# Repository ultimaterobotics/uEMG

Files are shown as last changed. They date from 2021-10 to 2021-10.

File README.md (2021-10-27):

# uEMG - 4-channel EMG device
This repository contains PCB design, firmware and PC program for analysing data (that one has hardly readable code for now, it's a work in progress with thousands lines of code dedicated to various signal processing approaches with only small part of them used in current version)

Firmware is in relatively good state. It depends on our nrf library: https://github.com/ultimaterobotics/urf_lib and requires bootloader: https://github.com/ultimaterobotics/uECG_bootloader

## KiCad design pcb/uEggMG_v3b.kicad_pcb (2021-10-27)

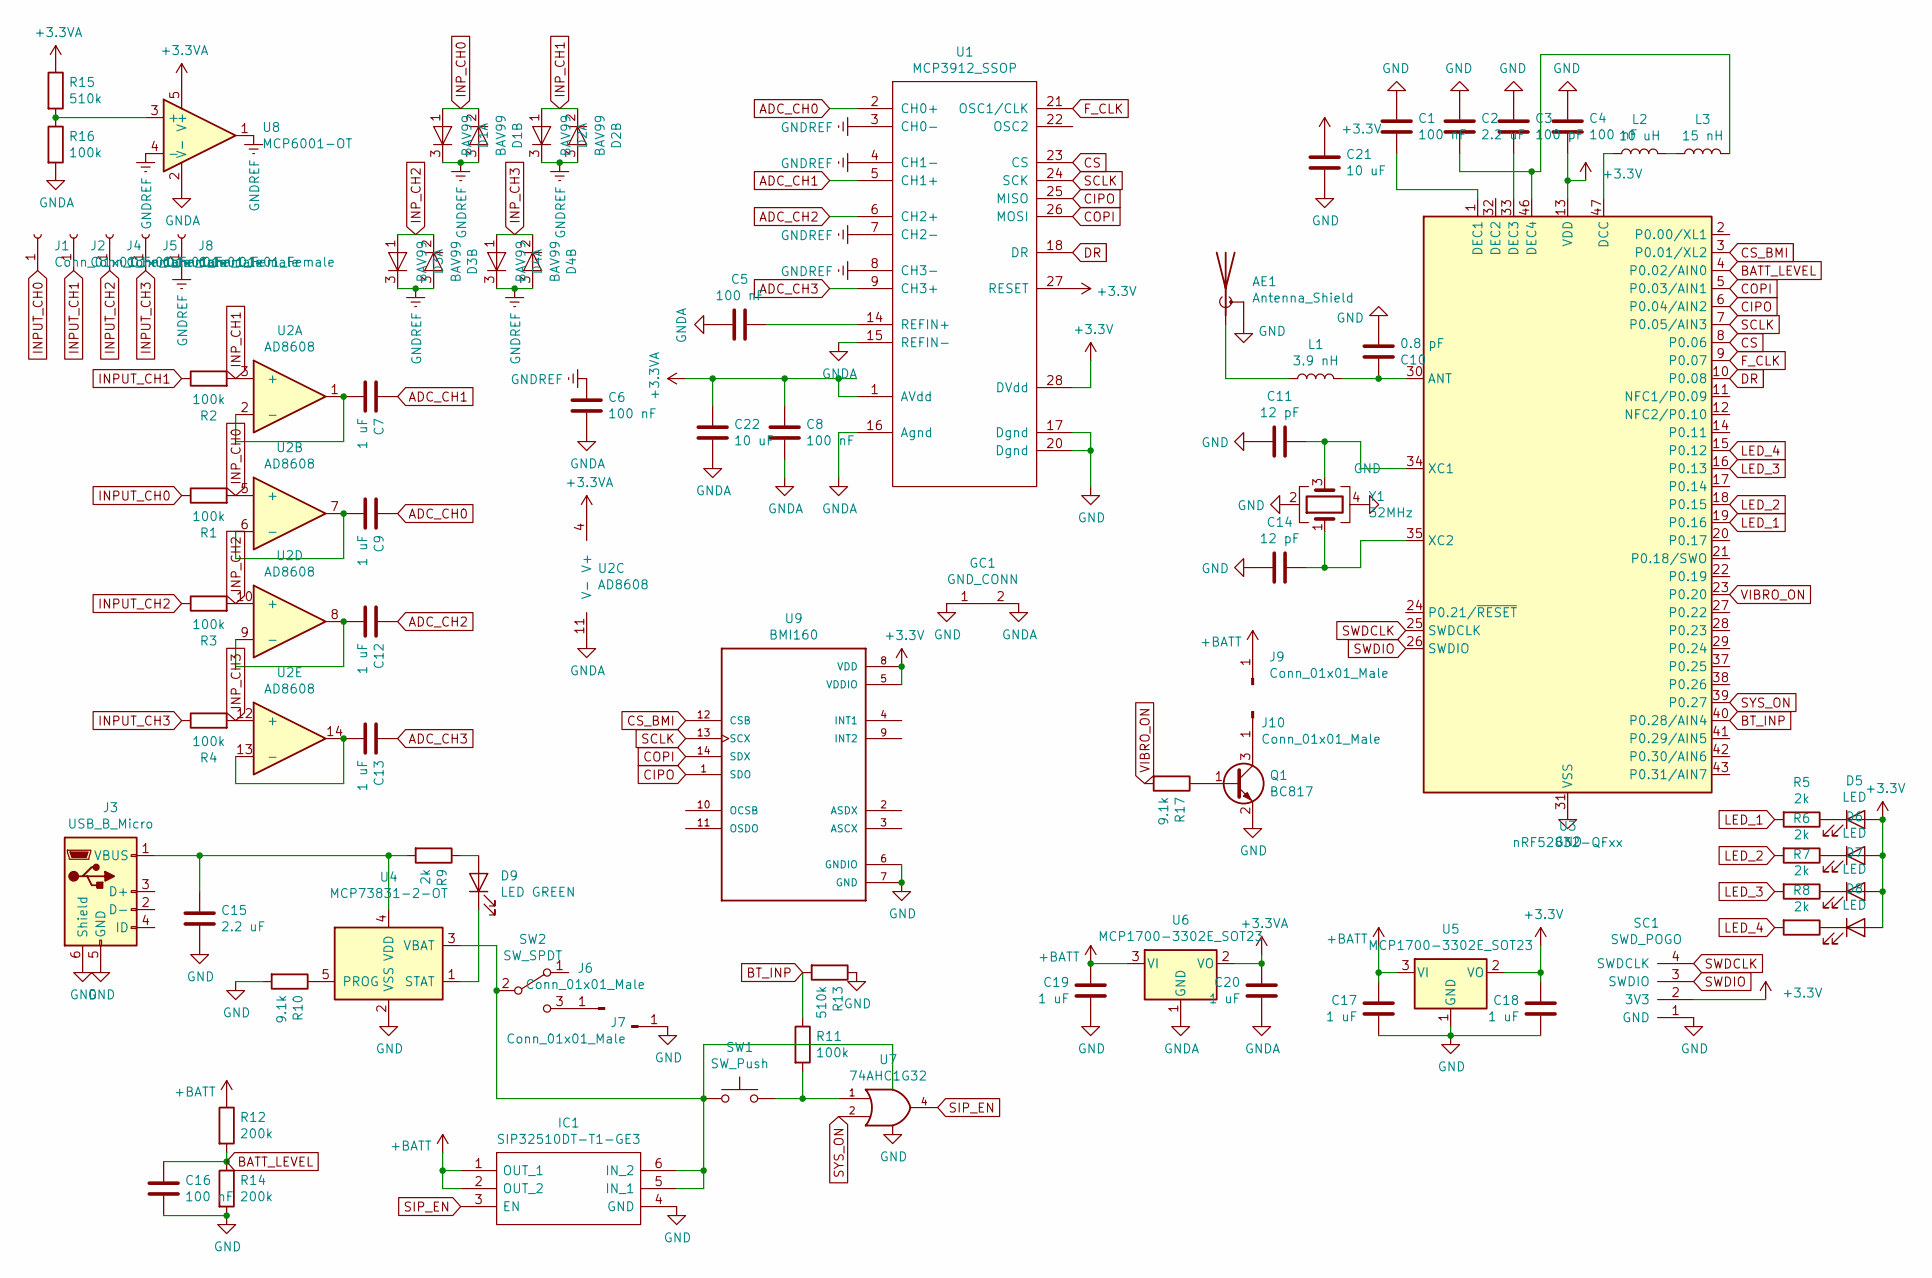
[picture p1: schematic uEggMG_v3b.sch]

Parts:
AE1: Antenna_Shield; U.FL_Hirose_U.FL-R-SMT-1_Vertical
C1, C4, C5, C6, C8, C16: 100 nF; C_0402_1005Metric
C2, C15: 2.2 uF; C_0402_1005Metric
C3: 100 pF; C_0402_1005Metric
C7, C9, C12, C13, C17, C18, C19, C20: 1 uF; C_0402_1005Metric
C10: 0.8 pF; C_0402_1005Metric
C11, C14: 12 pF; C_0402_1005Metric
C21, C22: 10 uF; C_0603_1608Metric
D1, D2, D3, D4: BAV99; SOT-23
D5, D6, D7, D8: LED; LED_0603_1608Metric
D9: LED GREEN; LED_0603_1608Metric
GC1: GND_CONN
IC1: SIP32510DT-T1-GE3; SOT95P284X110-6N; Manufacturer_Part_Number SIP32509DT-T1-GE3
J1, J2, J4, J5, J8: Conn_01x01_Female; textile_button_6mm
J3: USB_B_Micro; conn_usb_B_micro_smd_our
J6, J7, J9, J10: Conn_01x01_Male; PinHeader_1x01_P2.54mm_Vertical
L1: 3.9 nH; L_0402_1005Metric
L2: 10 uH; L_0603_1608Metric
L3: 15 nH; L_0402_1005Metric
Q1: BC817; SOT-23
R1, R2, R3, R4, R11, R16: 100k; R_0402_1005Metric
R5, R6, R7, R8, R9: 2k; R_0402_1005Metric
R10, R17: 9.1k; R_0402_1005Metric
R12, R14: 200k; R_0402_1005Metric
R13, R15: 510k; R_0402_1005Metric
SC1: SWD_POGO
SW1: SW_Push; BTN_HY_1185
SW2: SW_SPDT; SW_SPDT_PCM12
U1: MCP3912_SSOP; SSOP-28_5.3x10.2mm_P0.65mm
U2: AD8608; TSSOP-14_4.4x5mm_P0.65mm
U3: nRF52832-QFxx; QFN-48-1EP_6x6mm_Pitch0.4mm
U4: MCP73831-2-OT; SOT-23-5
U5, U6: MCP1700-3302E_SOT23; SOT-23
U7: 74AHC1G32; TSOT-23-5
U8: MCP6001-OT; SOT-23-5
U9: BMI160; PQFN50P300X250X88-14N
Y1: 32MHz; Crystal_SMD_2016-4Pin_2.0x1.6mm

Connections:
+3.3VA: C8.1, C20.2, C22.1, R15.1, U1.1 (AVdd), U2.4 (V+), U6.2 (VO), U8.5 (V+)
+3V3: C4.1, C18.2, C21.1, D5.2 (A), D6.2 (A), D7.2 (A), D8.2 (A), SC1.2 (3V3), U1.27 (RESET), U1.28 (DVdd), U3.13 (VDD), U3.36 (VDD), U3.48 (VDD), U5.2 (VO), U9.5 (VDDIO), U9.8 (VDD)
+BATT: C17.2, C19.2, IC1.1 (OUT_1), IC1.2 (OUT_2), J9.1, R12.1, U5.3 (VI), U6.3 (VI)
ADC_CH0: C9.1, U1.2 (CH0+)
ADC_CH1: C7.1, U1.5 (CH1+)
ADC_CH2: C12.1, U1.6 (CH2+)
ADC_CH3: C13.1, U1.9 (CH3+)
BATT_LEVEL: C16.2, R12.2, R14.1, U3.4 (P0.02/AIN0)
BT_INP: R11.1, R13.2, U3.40 (P0.28/AIN4)
CIPO: U1.25 (MISO), U3.6 (P0.04/AIN2), U9.1 (SDO)
COPI: U1.26 (MOSI), U3.5 (P0.03/AIN1), U9.14 (SDX)
CS: U1.23 (CS), U3.8 (P0.06)
CS_BMI: U3.3 (P0.01/XL2), U9.12 (CSB)
DR: U1.18 (DR), U3.10 (P0.08)
F_CLK: U1.21 (OSC1/CLK), U3.9 (P0.07)
GND: AE1.2 (Shield), C1.2, C2.2, C3.2, C4.2, C10.2, C11.1, C14.1, C15.1, C16.1, C17.1, C18.1, C19.1, C21.2, GC1.1, IC1.4 (GND), J3.5 (GND), J3.6 (Shield), J7.1, Q1.2 (E), R10.2, R13.1, R14.2, SC1.1 (GND), U1.17 (Dgnd), U1.20 (Dgnd), U3.31 (VSS), U3.45 (VSS), U3.49 (VSS), U4.2 (VSS), U5.1 (GND), U7.3 (GND), U9.6 (GNDIO), U9.7 (GND), Y1.2, Y1.4
GNDA: C5.2, C6.2, C8.2, C20.1, C22.2, GC1.2, R16.2, U1.10, U1.11, U1.12, U1.13, U1.15 (REFIN-), U1.16 (Agnd), U1.19, U2.11 (V-), U6.1 (GND), U8.2 (V-)
GNDREF: C6.1, D1.3 (K), D2.3 (K), D3.3 (K), D4.3 (K), J8.1, U1.3 (CH0-), U1.4 (CH1-), U1.7 (CH2-), U1.8 (CH3-), U8.1, U8.4 (-)
INPUT_CH0: J1.1, R1.1
INPUT_CH1: J2.1, R2.1
INPUT_CH2: J4.1, R3.1
INPUT_CH3: J5.1, R4.1
INP_CH0: D1.1 (A), D1.2 (K), R1.2, U2.5 (+)
INP_CH1: D2.1 (A), D2.2 (K), R2.2, U2.3 (+)
INP_CH2: D3.1 (A), D3.2 (K), R3.2, U2.10 (+)
INP_CH3: D4.1 (A), D4.2 (K), R4.2, U2.12 (+)
LED_1: R5.2, U3.19 (P0.16)
LED_2: R6.2, U3.18 (P0.15)
LED_3: R7.2, U3.16 (P0.13)
LED_4: R8.2, U3.15 (P0.12)
unnamed: AE1.1 (A), L1.1
unnamed: C1.1, U3.1 (DEC1)
unnamed: C2.1, L3.2, U3.46 (DEC4)
unnamed: C3.1, U3.33 (DEC3)
unnamed: C5.1, U1.14 (REFIN+)
unnamed: C7.2, U2.1, U2.2 (-)
unnamed: C9.2, U2.6 (-), U2.7
unnamed: C10.1, L1.2, U3.30 (ANT)
unnamed: C11.2, U3.34 (XC1), Y1.3
unnamed: C12.2, U2.8, U2.9 (-)
unnamed: C13.2, U2.13 (-), U2.14
unnamed: C14.2, U3.35 (XC2), Y1.1
unnamed: C15.2, J3.1 (VBUS), R9.2, U4.4 (VDD)
unnamed: D5.1 (K), R5.1
unnamed: D6.1 (K), R6.1
unnamed: D7.1 (K), R7.1
unnamed: D8.1 (K), R8.1
unnamed: D9.1 (K), U4.1 (STAT)
unnamed: D9.2 (A), R9.1
unnamed: J6.1, SW2.3 (C)
unnamed: J10.1, Q1.3 (C)
unnamed: L2.1, U3.47 (DCC)
unnamed: L2.2, L3.1
unnamed: Q1.1 (B), R17.1
unnamed: R10.1, U4.5 (PROG)
unnamed: R11.2, SW1.2, U7.1
unnamed: R15.2, R16.1, U8.3 (+)
SCLK: U1.24 (SCK), U3.7 (P0.05/AIN3), U9.13 (SCX)
SIP_EN: IC1.3 (EN), U7.4
SWDCLK: SC1.4 (SWDCLK), U3.25 (SWDCLK)
SWDIO: SC1.3 (SWDIO), U3.26 (SWDIO)
SYS_ON: U3.39 (P0.27), U7.2
VCC: IC1.5 (IN_1), IC1.6 (IN_2), SW1.1, SW2.2 (B), U4.3 (VBAT), U7.5 (VCC)
VIBRO_ON: R17.2, U3.23 (P0.20)

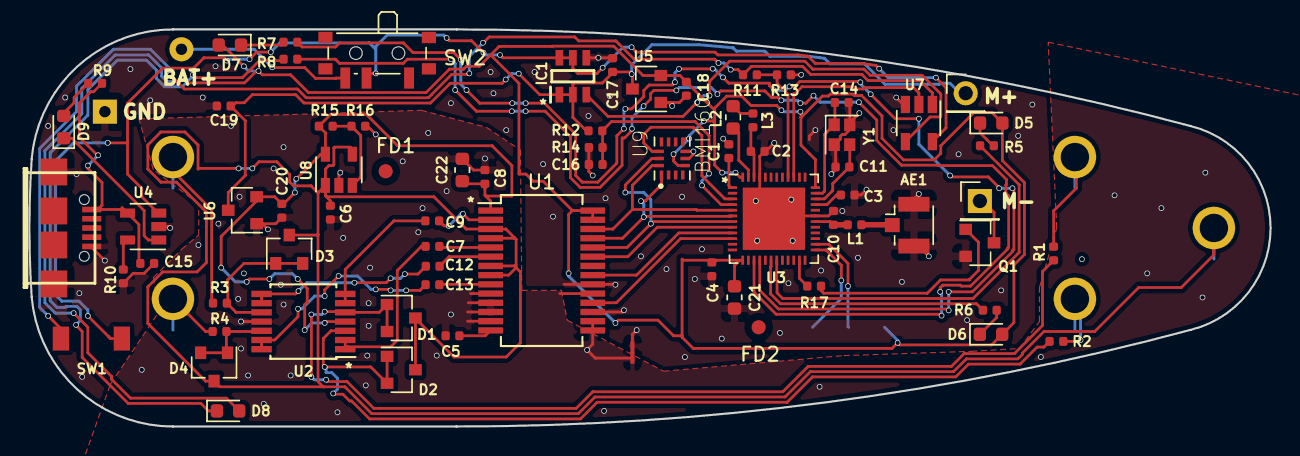
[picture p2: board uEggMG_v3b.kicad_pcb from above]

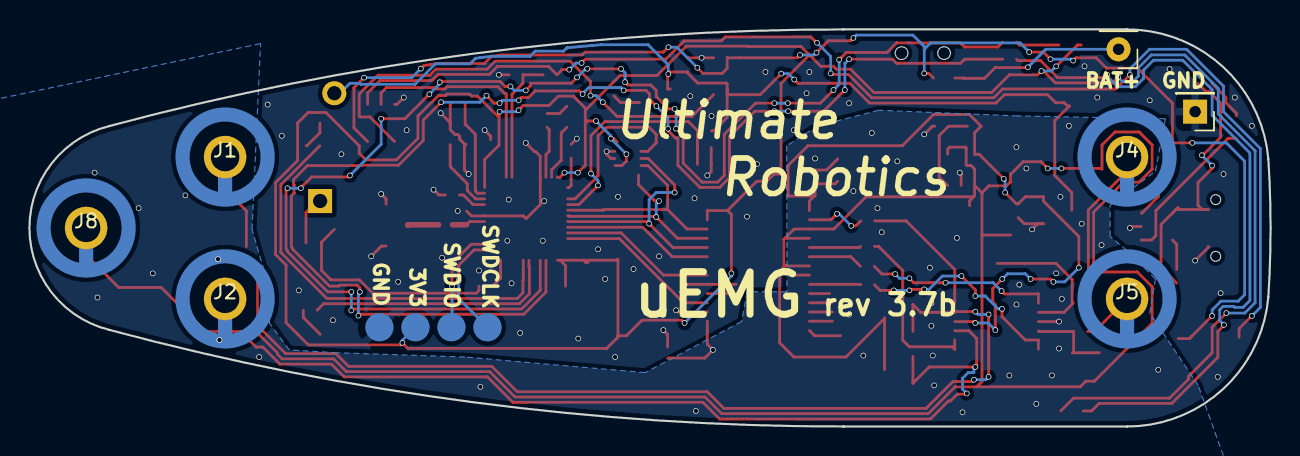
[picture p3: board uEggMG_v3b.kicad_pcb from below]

Board: 2 copper layers, 87.5 x 28.0 mm, 80 parts (8 on the bottom side), 64 nets.

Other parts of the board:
FD1, FD2: Fiducial_1mm_Dia_2mm_Outer

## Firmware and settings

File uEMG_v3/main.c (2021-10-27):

/**
 */

#include <stdbool.h>
#include <stdint.h>
#include <math.h>
#include "nrf.h"
#include "mcp3912.h"
#include "bmi160.h"
#include "leds.h"
#include "urf_star_protocol.h"
#include "urf_timer.h"
#include "imu_fusion.h"

//openocd -f interface/stlink-v2.cfg -f target/nrf52.cfg
//flash write_image erase _build/nrf52832_xxaa.hex

uint8_t pin_button = 28;
uint8_t pin_syson = 27;

float battery_mv = 3500; //by default non zero to prevent power off before actual measurement
int battery_low_threshold = 3200;

uint8_t battery_level = 0;
uint8_t packet_id = 0;
uint8_t data_packet[258];

uint8_t unsent_cnt = 0;

uint8_t mcp_data_id = 0;
int mcp_buffer[130];
uint8_t mcp_buf_pos = 0;
uint8_t mcp_buf_len = 128;
uint8_t mcp_cnt = 0;

uint8_t param_send_id = 0;

uint8_t emg_raw_data_send = 1;

enum param_sends
{
	param_batt = 0,
	param_imu_steps,
	param_end
};

uint8_t part2_packet = 0;

void prepare_data_packet()
{
	uint8_t idx = 0;
	packet_id++;
	if(packet_id > 128) packet_id = 0;
	data_packet[idx++] = packet_id;
	data_packet[idx++] = 0; //fill in the end
	uint32_t unit_id = NRF_FICR->DEVICEID[1];
	data_packet[idx++] = (unit_id>>24)&0xFF;
	data_packet[idx++] = (unit_id>>16)&0xFF;
	data_packet[idx++] = (unit_id>>8)&0xFF;
	data_packet[idx++] = (unit_id)&0xFF;
	uint8_t send_cnt = 16;
	if(emg_raw_data_send)
	{
		send_cnt = 32;
		data_packet[idx++] = 220+send_cnt;
	}
	else
	{
		if(part2_packet)
		{
			data_packet[idx++] = 100+send_cnt;
			part2_packet = 0;
		}
		else
			data_packet[idx++] = 200+send_cnt;
	}

	param_send_id++;
	if(param_send_id == param_end) param_send_id = 0;

	data_packet[idx++] = param_send_id;
	if(param_send_id == param_batt)
	{
		data_packet[idx++] = battery_level;
		data_packet[idx++] = 100; //version_id
		data_packet[idx++] = 0;
	}
	if(param_send_id == param_imu_steps)
	{
		sBMI160 *bmi = bmi160_get_data();
		int steps = bmi->step_cnt;
		data_packet[idx++] = (steps>>8)&0xFF;
		data_packet[idx++] = steps&0xFF;
		data_packet[idx++] = 0;
	}
	
	data_packet[idx++] = mcp_data_id;
	int start_cnt = mcp_buf_pos - send_cnt;
	if(start_cnt < 0) start_cnt += mcp_buf_len;
	for(int n = 0; n < send_cnt; n++)
	{
		data_packet[idx++] = mcp_buffer[start_cnt]>>8;
		data_packet[idx++] = mcp_buffer[start_cnt]&0xFF;
		start_cnt++;
		if(start_cnt >= mcp_buf_len) start_cnt = 0;
	}
	
//	if(!emg_raw_data_send)
	{
		sBMI160 *bmi = bmi160_get_data();
		int16_t b_ax = bmi->raX;
		int16_t b_ay = bmi->raY;
		int16_t b_az = bmi->raZ;
		data_packet[idx++] = (b_ax>>8)&0xFF;
		data_packet[idx++] = b_ax&0xFF;
		data_packet[idx++] = (b_ay>>8)&0xFF;
		data_packet[idx++] = b_ay&0xFF;
		data_packet[idx++] = (b_az>>8)&0xFF;
		data_packet[idx++] = b_az&0xFF;

		int16_t b_wx = bmi->rwX;
		int16_t b_wy = bmi->rwY;
		int16_t b_wz = bmi->rwZ;
		data_packet[idx++] = (b_wx>>8)&0xFF;
		data_packet[idx++] = b_wx&0xFF;
		data_packet[idx++] = (b_wy>>8)&0xFF;
		data_packet[idx++] = b_wy&0xFF;
		data_packet[idx++] = (b_wz>>8)&0xFF;
		data_packet[idx++] = b_wz&0xFF;
		
		sQ *cur_q = imu_fusion_get_q();
		b_wx = cur_q->x * 30000.0f;
		b_wy = cur_q->y * 30000.0f;
		b_wz = cur_q->z * 30000.0f;
		int16_t b_ww = cur_q->w * 30000.0f;
		data_packet[idx++] = (b_wx>>8)&0xFF;
		data_packet[idx++] = b_wx&0xFF;
		data_packet[idx++] = (b_wy>>8)&0xFF;
		data_packet[idx++] = b_wy&0xFF;
		data_packet[idx++] = (b_wz>>8)&0xFF;
		data_packet[idx++] = b_wz&0xFF;
		data_packet[idx++] = (b_ww>>8)&0xFF;
		data_packet[idx++] = b_ww&0xFF;
	}
	data_packet[1] = idx;
}

float avg_emg[4] = {0, 0, 0, 0};
int emg_lvl[4] = {0, 0, 0, 0};
int spectr_part2_pending = 0;
uint32_t spectr_part2_time = 0;
int mcp_buf_sp2[16];

int push_mcp_data()
{
//	if(emg_mode)	
	if(mcp_fft_process())
	{
		if(emg_raw_data_send)
		{
			float *dat_base = mcp_fft_get_raw();
			for(int c = 0; c < 4; c++)
			{
				float *dat = dat_base + c*8;
				for(int x = 0; x < 8; x++)
				{
					mcp_buffer[mcp_buf_pos++] = dat[x];
					if(mcp_buf_pos >= mcp_buf_len) mcp_buf_pos = 0;
				}
			}
		}
		else
		{
//			spectr_part2_pending = 1;
//			spectr_part2_time = millis();
			float *sp_base = mcp_fft_get_spectr();
			for(int c = 0; c < 4; c++)
			{
				float *sp = sp_base + c*8;

				float avg_center = 0;
				float low_part = 0;
				float high_part = 0;

				for(int x = 0; x < 4; x++)
				{
					if(x > 0) avg_center += sp[x];
					if(x == 0) low_part += sp[x];
					else high_part += sp[x];
					float vv = sp[x];
					if(vv < 0) vv = 0;
					if(vv > 65535) vv = 65535;
					mcp_buffer[mcp_buf_pos++] = vv;
					if(mcp_buf_pos >= mcp_buf_len) mcp_buf_pos = 0;

					float vv2 = sp[4+x];
					if(vv2 < 0) vv2 = 0;
					if(vv2 > 65535) vv2 = 65535;
					mcp_buf_sp2[c*4+x] = vv2;
				}
				
				
				low_part /= 2.0f;
				high_part /= 6.0f;
			
				float h_coeff = 2.0f*high_part / (low_part + high_part + 0.001f);

				avg_center *= 0.03f * h_coeff;
			
				avg_emg[c] *= 0.8f;
				avg_emg[c] += 0.2f*avg_center;

				emg_lvl[c] = avg_emg[c] * 100.0f;
				if(avg_emg[c] > 650) emg_lvl[c] = 65000;

			}
			static uint32_t last_led_ms = 0;
			uint32_t ms = millis();
			if(ms - last_led_ms > 30)
			{
				last_led_ms = ms;
				float led_scale = 1.0;
				int l1 = avg_emg[0] * led_scale;
				int l2 = avg_emg[1] * led_scale;
				int l3 = avg_emg[2] * led_scale;
				int l4 = avg_emg[3] * led_scale;
				if(l1 > 255) l1 = 255;
				if(l2 > 255) l2 = 255;
				if(l3 > 255) l3 = 255;
				if(l4 > 255) l4 = 255;
				leds_pulse(l1, l2, l3, l4, 100);
//				leds_pulse(255, 255, 0, 0, 100);
			}
		}
		mcp_data_id++;
//		leds_set(255*((ms%2000)>1000), 0, 0, 0);
		return 1;
	}
	return 0;
}


void fast_clock_start()
{
	NRF_CLOCK->EVENTS_HFCLKSTARTED = 0;
	NRF_CLOCK->TASKS_HFCLKSTART = 1;
	while (NRF_CLOCK->EVENTS_HFCLKSTARTED == 0) {}
}
void slow_clock_start()
{
	NRF_CLOCK->LFCLKSRC = 0;
	NRF_CLOCK->TASKS_LFCLKSTART = 1;
	while (NRF_CLOCK->EVENTS_LFCLKSTARTED == 0) {}
}
void fast_clock_stop()
{
	slow_clock_start();
//	NRF_CLOCK->EVENTS_LFCLKSTARTED = 0;
//	NRF_CLOCK->TASKS_LFCLKSTART = 1;
//	while (NRF_CLOCK->EVENTS_LFCLKSTARTED == 0) {}
	NRF_CLOCK->TASKS_HFCLKSTOP = 1;
}


void mode_lowbatt()
{
//	set_led(0);
//	nrf_delay_ms(1);
//	mcp3912_turnoff();
	time_stop();
	fast_clock_stop();
	NRF_SPI0->ENABLE = 0;
	leds_pulse(0, 0, 0, 0, 1);
	delay_ms(2);
	NRF_GPIO->OUTCLR = 1<<pin_syson;
//	nrf_delay_ms(1);
	NRF_POWER->TASKS_LOWPWR = 1;
//	NRF_POWER->DCDCEN = 1;
	NRF_POWER->SYSTEMOFF = 1;
}
void stop_rtc()
{
	NRF_RTC1->TASKS_STOP = 1;
}
void start_rtc()
{
	stop_rtc();
	NRF_RTC1->TASKS_CLEAR = 1;
	NRF_RTC1->CC[0] = 220;
	NRF_RTC1->CC[1] = 0xFFFF;
	NRF_RTC1->CC[2] = 0xFFFF;
	NRF_RTC1->CC[3] = 0xFFFF;
	NRF_RTC1->PRESCALER = 0x3CFFFF;
	NRF_RTC1->INTENSET = (1<<16); //CC0 event
	NVIC_EnableIRQ(RTC1_IRQn);
	NRF_RTC1->TASKS_START = 1;
}
void RTC1_IRQHandler(void)
{
	/* Update compare counter */
	if (NRF_RTC1->EVENTS_COMPARE[0] != 0)
	{
		NRF_RTC1->EVENTS_COMPARE[0] = 0;
		NRF_RTC1->TASKS_CLEAR = 1;  // Clear Counter		    
//		if(U32_delay_ms) U32_delay_ms--; // used in V_hw_delay_ms()
		__SEV(); // to avoid race condition
		stop_rtc();
	}
}

void read_battery()
{
	
	uint32_t result = 0;
	
	// Configure SAADC singled-ended channel, Internal reference (0.6V) and 1/6 gain.
	NRF_SAADC->CH[0].CONFIG = (SAADC_CH_CONFIG_GAIN_Gain1_6    << SAADC_CH_CONFIG_GAIN_Pos) |
							(SAADC_CH_CONFIG_MODE_SE         << SAADC_CH_CONFIG_MODE_Pos) |
							(SAADC_CH_CONFIG_REFSEL_Internal << SAADC_CH_CONFIG_REFSEL_Pos) |
							(SAADC_CH_CONFIG_RESN_Bypass     << SAADC_CH_CONFIG_RESN_Pos) |
							(SAADC_CH_CONFIG_RESP_Bypass     << SAADC_CH_CONFIG_RESP_Pos) |
							(SAADC_CH_CONFIG_TACQ_3us        << SAADC_CH_CONFIG_TACQ_Pos);

	// Configure the SAADC channel with VDD as positive input, no negative input(single ended).
	NRF_SAADC->CH[0].PSELP = SAADC_CH_PSELP_PSELP_AnalogInput0 << SAADC_CH_PSELP_PSELP_Pos;
	NRF_SAADC->CH[0].PSELN = SAADC_CH_PSELN_PSELN_NC << SAADC_CH_PSELN_PSELN_Pos;

	// Configure the SAADC resolution.
	NRF_SAADC->RESOLUTION = SAADC_RESOLUTION_VAL_14bit << SAADC_RESOLUTION_VAL_Pos;

	// Configure result to be put in RAM at the location of "result" variable.
	NRF_SAADC->RESULT.MAXCNT = 1;
	NRF_SAADC->RESULT.PTR = (uint32_t)&result;

	// No automatic sampling, will trigger with TASKS_SAMPLE.
	NRF_SAADC->SAMPLERATE = SAADC_SAMPLERATE_MODE_Task << SAADC_SAMPLERATE_MODE_Pos;

	// Enable SAADC (would capture analog pins if they were used in CH[0].PSELP)
	NRF_SAADC->ENABLE = SAADC_ENABLE_ENABLE_Enabled << SAADC_ENABLE_ENABLE_Pos;


	static int cal_cnt = 0;
	cal_cnt++;
	if(0)if(cal_cnt > 1000)
	{
		cal_cnt = 0;
		// Calibrate the SAADC (only needs to be done once in a while)
		NRF_SAADC->TASKS_CALIBRATEOFFSET = 1;
		while (NRF_SAADC->EVENTS_CALIBRATEDONE == 0);
		NRF_SAADC->EVENTS_CALIBRATEDONE = 0;
		while (NRF_SAADC->STATUS == (SAADC_STATUS_STATUS_Busy <<SAADC_STATUS_STATUS_Pos));
	}

	// Start the SAADC and wait for the started event.
	NRF_SAADC->TASKS_START = 1;
	while (NRF_SAADC->EVENTS_STARTED == 0);
	NRF_SAADC->EVENTS_STARTED = 0;

	// Do a SAADC sample, will put the result in the configured RAM buffer.
	NRF_SAADC->TASKS_SAMPLE = 1;
	while (NRF_SAADC->EVENTS_END == 0);
	NRF_SAADC->EVENTS_END = 0;

// Convert the result to voltage
// Result = [V(p) - V(n)] * GAIN/REFERENCE * 2^(RESOLUTION)
// Result = (VDD - 0) * ((1/6) / 0.6) * 2^14
// VDD = Result / 4551.1
//  precise_result = (float)result / 4551.1f;
//  precise_result; // to get rid of set but not used warning

	// Stop the SAADC, since it's not used anymore.
	NRF_SAADC->TASKS_STOP = 1;
	while (NRF_SAADC->EVENTS_STOPPED == 0);
	NRF_SAADC->EVENTS_STOPPED = 0;
	
	float res = result;
	//16384 = 3600 mV on A0
	res = res * 3600.0f / 16384.0f; //now res is in mv
	res *= 2.0f; //1:2 divider on the battery measurement
	battery_mv = res;
	res -= 2000.0f; //everything below 2V is too low for a battery
	if(res < 0)
	{
		battery_level = 0;
		return;
	}
	if(res > 2550) //shouldn't ever happen - 4.55v on the battery is way too much
	{
		battery_level = 255;
		return;
	}
	battery_level = res / 10;
	return;
}


void mode_idle()
{
//	leds_pause();
	time_pause();
	NRF_POWER->TASKS_LOWPWR = 1;
}
void mode_resume_idle()
{
	NRF_POWER->TASKS_CONSTLAT = 1;
	time_resume();
//	leds_resume();
}

void low_power_cycle()
{
	NRF_RADIO->POWER = 0;
//	mode_idle();
	__WFI();
//	mode_resume_idle();
	NRF_RADIO->POWER = 1;
}


enum
{
	radio_mode_fast = 0,
	radio_mode_ble,
	radio_mode_fast64
};

uint8_t radio_mode = radio_mode_fast64;//radio_mode_ble;
/*
void RADIO_IRQHandler()
{
	if(radio_mode == radio_mode_fast || radio_mode == radio_mode_fast64)
		fr_irq_handler();
	if(radio_mode == radio_mode_ble)
		ble_irq_handler();
}*/

void switch_to_ble()
{
//	fr_disable();
//	fr_poweroff();
//	config_ble_adv();
}

void switch_to_fr32()
{
//	fr_disable();
//	fr_poweroff();
//	fr_init(32);
//	fr_listen();	
}

void switch_to_fr48()
{
//	fr_disable();
//	fr_poweroff();
//	fr_init(48);
//	fr_listen();	
}
void switch_to_fr64()
{
//	fr_disable();
//	fr_poweroff();
//	fr_init(64);
//	fr_listen();	
}

void process_btn_short()
{
	emg_raw_data_send = !emg_raw_data_send;
/*	if(radio_mode == radio_mode_ble)
	{
		radio_mode = radio_mode_fast64;
		switch_to_fr64();
	}
	else if(radio_mode == radio_mode_fast64)
	{
		radio_mode = radio_mode_fast;
		switch_to_fr32();
	}
	else
	{
		radio_mode = radio_mode_ble;
		switch_to_ble();
	}*/
}

void process_btn_long()
{
	NRF_GPIO->OUTCLR = 1<<pin_syson;
}

int main(void)
{
	int init_ok = 1;
	
	NRF_UICR->NFCPINS = 0;

	NRF_GPIO->PIN_CNF[pin_button] = 0;

	fast_clock_start();
	time_start();
	NRF_GPIO->DIRSET = 1<<pin_syson;
	NRF_GPIO->OUTSET = 1<<pin_syson;
	leds_init();

//	NRF_POWER->DCDCEN = 1;

	for(int x = 0; x < 4; x++)
	{
		leds_pulse((x==0)*255, (x==1)*255, (x==2)*255, (x==3)*255, 250);
		delay_ms(300);
	}
//	leds_set_driver(55);
//	leds_set(255, 60, 120);
//	leds_set(0, 0, 0, 0);
//	delay_ms(300);

//	if(radio_mode == radio_mode_ble)
//		config_ble_adv();
//	if(radio_mode == radio_mode_fast)
//	{
//		fr_init(32);
//		fr_listen();
//	}
//	if(radio_mode == radio_mode_fast64)
//	{
//		fr_init(64);
//		fr_listen();
//	}
	star_init(21, 1000, 2000, 0);

	leds_pulse(255, 255, 255, 0, 200);
	
	init_mcp3912(4, 3, 5, 6, 8);
	leds_pulse(0, 0, 0, 0, 10);
	if(!mcp3912_is_ok())
	{
		init_ok = 0;
		leds_pulse(255, 0, 0, 0, 1000);
		delay_ms(1200);
		leds_pulse(255, 0, 255, 0, 1000);
		delay_ms(1200);
	}
	bmi160_init(4, 3, 5, 1, 20);
	if(!bmi160_is_ok())
	{
		init_ok = 0;
		leds_pulse(255, 0, 0, 0, 1000);
		delay_ms(1200);
		leds_pulse(255, 255, 0, 0, 1000);
		delay_ms(1200);
	}
	if(NRF_GPIO->IN & 1<<pin_button)
	{
		leds_pulse(255, 0, 0, 0, 1000);
		delay_ms(1200);
		leds_pulse(0, 0, 255, 0, 1000);
		delay_ms(1200);
	}
	

//	leds_set(0, 255, 0);

	delay_ms(100);

	uint32_t last_sent_ms = 0;
	uint32_t btn_on = 0;
	uint32_t btn_off = 0;

	NRF_RNG->TASKS_START = 1;
	NRF_RNG->SHORTS = 0;
	NRF_RNG->CONFIG = 1;
	
	int ble_dt1 = 5;
	int ble_dt2 = 5;
	int send_iter = 0;
	int low_bat_cnt = 0;
	
	int bmi_skip_cnt = 0;
		
	if(init_ok)
	{
		for(int x = 0; x < 3; x++)
		{
			leds_pulse(255, 255, 0, 0, 200);
			delay_ms(200);
			leds_pulse(0, 0, 255, 255, 200);
			delay_ms(200);
		}
	}
	
	uint32_t unit_id = NRF_FICR->DEVICEID[1];
	uint32_t last_rx_packet_time = 0;
	
	star_set_id(unit_id);
	
	int btn_pressed = 0;
	
	imu_fusion_init();

	NRF_WDT->CRV = 1*32768; //1 second timeout
	NRF_WDT->TASKS_START = 1;

	while(1)
	{
		NRF_WDT->RR[0] = 0x6E524635; //reload watchdog
		star_loop_step();
//		low_power_cycle();
		uint32_t ms = millis();
		
		if(NRF_GPIO->IN & 1<<pin_button)
		{
			if(!btn_pressed)
			{
				btn_pressed = 1;
				btn_on = ms;
			}
			if(ms - btn_on > 25 && ms - btn_on < 1000)
				leds_pulse(0, 0, 255, 0, 30);
			if(ms - btn_on > 1000 && ms - btn_on < 5000)
				leds_pulse(0, 255, 0, 0, 30);
			if(ms - btn_on > 5000)
				leds_pulse(255, 255, 255, 255, 30);
		}
		else
		{
			if(btn_pressed)
			{
				btn_pressed = 0;
				btn_off = ms;
				leds_pulse(0, 0, 0, 0, 10);
				uint32_t btn_time = btn_off - btn_on;
				if(btn_time > 25) //ignore too short presses - noise
				{
					if(btn_time < 1000)
						process_btn_short();
					else if(btn_time < 5000)
						process_btn_long();
				}
//				mcp_set_filter_mode(radio_mode == radio_mode_ble);
			}
		}

/*		if(spectr_part2_pending && millis() - spectr_part2_time > 4)
		{
			for(int x = 0; x < 16; x++)
			{
				mcp_buffer[mcp_buf_pos++] = mcp_buf_sp2[x];
				if(mcp_buf_pos >= mcp_buf_len) mcp_buf_pos = 0;
			}
			spectr_part2_pending = 0;
			part2_packet = 1;
			if(unsent_cnt < 30) unsent_cnt++;
//			return 1;
		}*/
		
		if(mcp3912_read())
		{
			if(push_mcp_data())
			{
				mcp_cnt++;
//				data_id++;
				int mcp_cnt_led = (mcp_cnt>>6)%4;
//				leds_set(255*(mcp_cnt_led==0), 255*(mcp_cnt_led==1), 255*(mcp_cnt_led==2), 255*(mcp_cnt_led==3));
				
				if(unsent_cnt < 30) unsent_cnt++;
				read_battery();
/*				if(battery_mv < battery_low_threshold)
				{
					low_bat_cnt++;
					if(low_bat_cnt > 100)
						mode_lowbatt();
				}
				else
					low_bat_cnt = 0;*/
			}
//			if(!emg_mode)
			{
				imu_fusion_process();
//				bmi160_read();
				bmi_skip_cnt++;
				if(bmi_skip_cnt == 100)
				{
					bmi160_read_temp();
				}
				if(bmi_skip_cnt > 200)
				{
					bmi160_read_steps();
					bmi_skip_cnt = 0;
				}
			}
/*			if(0)if(fft_pending())
			{
				fft_skip_cnt++; 
				if(fft_skip_cnt > 0)
				{
//					sfft_butterfly();
					int cv = 10 + get_avg_sp();
					//if(cv > spectr_val && cv < 400) 
						spectr_val = cv;
					fft_skip_cnt = 0;
				}
			}*/
			
		}		

		if(radio_mode == radio_mode_fast64)
		{
			if(unsent_cnt > 0)
			{
				prepare_data_packet();
				star_queue_send(data_packet, data_packet[1]);
//				rf_send_and_listen(data_packet, data_packet[1]);
				last_sent_ms = ms;
				unsent_cnt = 0;
			}
		}
	}

}

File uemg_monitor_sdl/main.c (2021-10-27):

#pragma GCC diagnostic error "-Wimplicit-function-declaration"

#include <stdio.h>
#include <string.h>
#include <stdint.h>

#include "serial_functions.h"
#include "device_functions.h"

#include <SDL/SDL.h>
#include <SDL/SDL_ttf.h>
#include <sys/time.h> 
#include <X11/Xlib.h>

#include "save_processing.h"
#include "drawing.h"

#include "qr_factorize.h"

int use_fullscreen = 0;

SDL_Surface *scr;

int W;
int H;

void get_scr_res(int *w, int *h)
{
    Display *display;
    Screen *screen;

    // open a display
    display = XOpenDisplay(NULL);

    // return the number of available screens
    int count_screens = ScreenCount(display);

	if(count_screens < 1) printf("no screen found!\n");
	screen = ScreenOfDisplay(display, 0);
	printf("screen %dX%d\n", screen->width, screen->height);
    // close the display
	*w = screen->width;
	*h = screen->height;
    XCloseDisplay(display);	
}

void prepareOut(int w, int h)
{	
	SDL_Init(SDL_INIT_VIDEO);

	W = w;
	H = h;
	int ok;
	if(use_fullscreen)
		ok = SDL_VideoModeOK(W, H, 32, SDL_DOUBLEBUF|SDL_HWSURFACE|SDL_FULLSCREEN);
	else
		ok = SDL_VideoModeOK(W, H, 32, SDL_DOUBLEBUF|SDL_HWSURFACE);
	printf("mode isok: %d\n", ok);
	if(use_fullscreen)
		scr = SDL_SetVideoMode(W, H, 32, SDL_DOUBLEBUF|SDL_HWSURFACE|SDL_FULLSCREEN);
	else
		scr = SDL_SetVideoMode(W, H, 32, SDL_DOUBLEBUF|SDL_HWSURFACE);
	if(scr == NULL)
		printf("can't create video out\n");
	else
		printf("scr: %d x %d, %d\n", scr->w, scr->h, scr->format->BitsPerPixel);
}

int outBuf = 0;


void drawFrameM(uint8_t *drawBuf)
{
	SDL_LockSurface(scr);
	uint8_t *impix = (uint8_t*)scr->pixels;
	memcpy(impix, drawBuf, W*H*4);
	SDL_UnlockSurface(scr);
}

void drawFrame(uint8_t *drawBuf)
{
	SDL_LockSurface(scr);
	uint8_t *impix = (uint8_t*)scr->pixels;
	memcpy(impix, drawBuf, W*H*4);
	SDL_UnlockSurface(scr);
	SDL_Flip(scr);
}

TTF_Font *font = NULL; 
TTF_Font *fontSS = NULL; 
TTF_Font *fontSM = NULL; 
TTF_Font *fontSL = NULL; 

enum
{
	mode_serial = 0,
	mode_telnet
};

int emulated_mode = 0;

void main_loop(uint32_t* scr_buf)
{
	draw_loop(scr_buf);
	if(emulated_mode)
		device_emulate_step();
	else
		serial_main_loop();
}
#include "pca_processor.h"

float pca_sample_data[21*20] = {
1.355398384,1.855398384,1.194326925,1.694326925,1.245091803,1.269578406,1.769578406,1.008569164,1.508569164,1.270962641,1.770962641,1.305253314,1.377767271,1.877767271,0.362564971,0.862564971,0.018640427,0.518640427,0.141775135,0.31199387,0.81199387,
0.468017899,0.968017899,0.345197471,0.845197471,0.499484174,0.043460726,0.543460726,1.242070991,1.742070991,1.126649743,1.626649743,1.135932591,1.496907106,1.996907106,0.003283945,0.503283945,0.010236346,0.510236346,0.413119674,0.413971662,0.913971662,
1.104673551,1.604673551,1.234425148,1.734425148,1.195437475,1.396538386,1.896538386,1.036208694,1.536208694,1.275875717,1.775875717,1.326348737,1.018970062,1.518970062,1.389841833,1.889841833,1.284184248,1.784184248,1.35513169,1.222155152,1.722155152,
3.091759922,3.591759922,3.408942775,3.908942775,3.384487161,3.401118373,3.901118373,0.060393263,0.560393263,0.488165655,0.988165655,0.000948232,0.227534142,0.727534142,3.237208139,3.737208139,3.018610047,3.518610047,3.433719652,3.008308391,3.508308391,
7.423130337,7.923130337,7.088488859,7.588488859,7.100479331,7.102792547,7.602792547,0.104278574,0.604278574,0.003791937,0.503791937,0.273062809,0.240466944,0.740466944,7.068574544,7.568574544,7.475870625,7.975870625,7.079527441,7.285700592,7.785700592,
9.329782976,9.829782976,9.367496962,9.867496962,9.334956581,9.013695803,9.513695803,1.301912942,1.801912942,1.318178503,1.818178503,1.001845926,1.254130415,1.754130415,9.309425657,9.809425657,9.003999478,9.503999478,9.093795134,9.077164332,9.577164332,
6.31278568,6.81278568,6.441074326,6.941074326,6.335146084,6.006251892,6.506251892,0.287600108,0.787600108,0.055208525,0.555208525,0.4132655,0.002949054,0.502949054,6.499334685,6.999334685,6.412249224,6.912249224,6.407437411,6.354819526,6.854819526,
4.235015601,4.735015601,4.316022256,4.816022256,4.269757504,4.463448108,4.963448108,0.046026309,0.546026309,0.469750149,0.969750149,0.064891945,0.226734295,0.726734295,4.403094124,4.903094124,4.12558547,4.62558547,4.19736108,4.404335696,4.904335696,
2.462931835,2.962931835,2.030900886,2.530900886,2.16334131,2.233202566,2.733202566,1.350544234,1.850544234,1.056226315,1.556226315,1.447158433,1.227413409,1.727413409,2.299441732,2.799441732,2.454078377,2.954078377,2.102398006,2.352375702,2.852375702,
1.307054461,0.807054461,1.446211724,0.946211724,1.183136074,1.15878546,0.65878546,0.111203413,-0.388796587,0.070994723,-0.429005277,0.437361101,0.295931684,-0.204068316,1.352880482,0.852880482,1.489773306,0.989773306,1.432060834,1.339500869,0.839500869,
1.226089146,0.726089146,1.124622139,0.624622139,1.411909074,1.331447691,0.831447691,1.425398221,0.925398221,1.473740306,0.973740306,1.161498973,1.012090752,0.512090752,1.344583353,0.844583353,1.439887365,0.939887365,1.183983451,1.141140663,0.641140663,
1.082043723,0.582043723,1.024630356,0.524630356,1.097489804,1.317442588,0.817442588,1.282926151,0.782926151,1.41595788,0.91595788,1.139255031,1.350797765,0.850797765,1.363516012,0.863516012,1.394184564,0.894184564,1.499937914,1.214389008,0.714389008,
0.448164919,-0.051835081,0.467446984,-0.032553016,0.363884496,0.144373882,-0.355626118,3.026679345,2.526679345,3.420906766,2.920906766,3.189901972,3.370143135,2.870143135,3.010886552,2.510886552,3.344221508,2.844221508,3.045581418,3.172236588,2.672236588,
0.233519694,-0.266480306,0.267557938,-0.232442062,0.125943825,0.330681689,-0.169318311,7.048769479,6.548769479,7.250352321,6.750352321,7.221508761,7.359471686,6.859471686,7.368303694,6.868303694,7.440054536,6.940054536,7.483144438,7.03920846,6.53920846,
1.472016133,0.972016133,1.461439624,0.961439624,1.250262581,1.42089083,0.92089083,9.419352075,8.919352075,9.272820007,8.772820007,9.0686153,9.444377831,8.944377831,9.168785632,8.668785632,9.377813953,8.877813953,9.421838719,9.038914533,8.538914533,
0.302323597,-0.197676403,0.014860282,-0.485139718,0.119788777,0.077804543,-0.422195457,6.279904221,5.779904221,6.196824403,5.696824403,6.219543265,6.20375489,5.70375489,6.456495649,5.956495649,6.450269756,5.950269756,6.226056902,6.033578939,5.533578939,
0.084448342,-0.415551658,0.351836792,-0.148163208,0.213097435,0.361274506,-0.138725494,4.136559964,3.636559964,4.451892737,3.951892737,4.32793968,4.035681275,3.535681275,4.226005489,3.726005489,4.319795765,3.819795765,4.038685294,4.106379,3.606379,
1.367544348,0.867544348,1.234283513,0.734283513,1.434706684,1.294397904,0.794397904,2.466139903,1.966139903,2.442851444,1.942851444,2.313951478,2.177196548,1.677196548,2.339981275,1.839981275,2.134642229,1.634642229,2.427319676,2.340406034,1.840406034,
0.03992922,-0.46007078,0.228300337,-0.271699663,0.179047524,0.43154261,-0.06845739,1.067126871,0.567126871,1.167952922,0.667952922,1.366969851,1.006555733,0.506555733,1.474634118,0.974634118,1.060597694,0.560597694,1.111982827,1.25217034,0.75217034,
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

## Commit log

2020-06-19 v1 pcb design
    [uEMG_v1.kicad_pcb, uEMG_v1.sch]
2021-10-27 complete new versionuploaded, replacing old PCB and adding firmware, PC code
    [uEMG_v1.kicad_pcb, uEMG_v1.sch, uEggMG_v3b.kicad_pcb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]
